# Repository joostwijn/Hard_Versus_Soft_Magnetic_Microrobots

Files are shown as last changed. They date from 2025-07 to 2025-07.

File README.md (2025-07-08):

# Hard_Versus_Soft_Magnetic_Microrobots

This repository supports the paper *"Propulsion Performance Comparison of Hard- and Soft-Magnetic Microrobots Under Rotating Magnetic Fields."* 
It contains all files needed to reproduce the experimental setup, control electronics, magnetic array optimization, and microrobot designs.

**Repository Structure**  
The repository is divided into four main chapters:

**1. Rotating Magnetic Field Setup** – All parts, bill of materials, SolidWorks assembly files, STL files for 3D printing, and DXF files for laser cutting.  
**2. Electronics** – Wiring diagrams, manuals for the electronic components, Arduino code, and Nextion display code.  
**3. Magnetic Optimization Code** – Python script for optimizing the magnetic array.  
**4. Microrobots** – Microrobot designs, STL files, and pre-configured Formlabs files.

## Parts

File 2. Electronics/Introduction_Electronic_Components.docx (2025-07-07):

This file contains a brief explanation of the different electronic components used in the Rotating Magnetic Setup. These components include the 12V/5A power supply, Arduino UNO R3, Nema 17 stepper motor, DRV8825 stepper driver, and Nextion display 2.4 inch (NX3224T024). The wiring of these components can be found in the file ”Wire_Diagram”.

12V/5A power supply
The system is powered by a 12V/5A power supply, which in turn is connected to a 230V mains socket. For safety and convenience, the 230V supply first passes through a three-pin fused switch connector before reaching the power supply.
To protect the electronics from damaging voltage spikes, a 100μF (rated at 50V) capacitor is placed across the 12V power supply’s positive and negative terminals, mitigating any surge that might otherwise harm the components.
The 12V output is distributed in two ways: it directly powers the stepper motor and supplies the Arduino UNO R3.

Arduino UNO R3
The Arduino UNO R3 is used to communicate with the Nextion display and uses the Nextion’s input to drive the stepper motor. The Arduino is programmed using C++ in the dedicated Arduino IDE (https://www.arduino.cc/en/software). The Arduino features an onboard step-down converter that supports up to 12V, allowing it to operate safely while maintaining the ability to upload code via USB. When a USB cable is connected, the Arduino automatically switches to USB power. The Arduino’s regulated 5V output is used to power both the Nextion display and the stepper driver.

NEMA 17 stepper motor
The NEMA 17 stepper motor is powered directly by the 12V power supply and controlled through a stepper driver. The Arduino UNO sends pulse signals to the stepper driver based on input from the Nextion display, determining the motor's speed and direction. The NEMA 17 can deliver a torque of up to 5.0 kg·cm (0.49 N·m). If higher torque is required, a NEMA 23 stepper motor can be used, but this requires a different stepper driver.

The NEMA 17 generates significant noise and vibrations at low rotation speeds. These can be reduced by enabling microstepping (smaller steps result in fewer vibrations), lowering the current limit on the stepper driver (see next paragraph), and including rubber O-rings in the stepper motor mounting.

DRV8825 stepper driver
The DRV8825 stepper motor driver receives pulse signals from the Arduino UNO to control the NEMA 17 stepper motor. It supports microstepping up to 1/32 steps and operates at 8.2V to 45V, supplying up to 2.5A per coil with sufficient cooling. The current limit must be manually set using the build-in potentiometer to match the motor's rated current (see https://www.makerguides.com/drv8825-stepper-motor-driver-arduino-tutorial/ for instructions). A heatsink or active cooling is required at high currents (<1 A) to prevent overheating.

Nextion display 2.4 inch (NX3224T024)
The Nextion 2.4-inch (NX3224T024) display is a resistive touchscreen that operates independently from the Arduino. It communicates with the Arduino via a hexadecimal protocol, sending commands for speed, direction, and the number of turns the stepper motor should complete.

Using a separate UI module reduces processing load on the Arduino and enables independent display operation. The Nextion is programmed using the Nextion Editor, which provides a graphical interface for designing screens and handling interactions (https://nextion.tech/editor_guide/).

Code uploads require an ADLivery CP2102 USB-to-serial adapter, along with its corresponding driver (https://www.silabs.com/developer-tools/usb-to-uart-bridge-vcp-drivers?tab=downloads). Proper installation of the driver is necessary for successful communication between the computer and the display.

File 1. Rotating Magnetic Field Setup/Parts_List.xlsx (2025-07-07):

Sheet: Structural_Components
Component | Quantity | Notes
20x20x500 aluminum profile | 2
20x40x160 aluminum profile | 5
Angle backets 20x20 | 14
Nema-17 angle bracket | 1
O-ring 28x3.1 | 6 | Supports for the setup to reduce vibrations and noise
O-ring 6x1.9 | 4 | Used as washers for the mounting screws of the stepper motor to reduce vibrations and noise
Washer M5 | 45
T-nut M5 | 45
Nut M3 | 9
Hex. socket screw M5x12 | 45
Hex. socket screw M3x6 | 17
Hex. socket screw M3x8 | 2
Hex. socket screw M3x20 | 1
Hex. Bolt M3x8 | 4
Threaded inserts M3x4x5 | 8
Nylon M3x12 screw | 4
Nylon M3 nut | 4

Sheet: Manufactured_Parts
Component | Quantity | Manufacturing technique | Material
Electronics mounting plate | 1 | 3D printing (FDM) | PLA
Stepper motor coupling | 1 | 3D printing (FDM) | PLA
Axis coupling | 1 | 3D printing (FDM) | PLA
Magnetic array | 2 | 3D printing (FDM) | PLA
Hollow Axis | 1 | 3D printing (FDM) | PLA
Tube setter | 1 | 3D printing (FDM) | PLA
Tube cap | 2 | 3D printing (FDM) | PLA
Back plate electronic casing | 1 | Laser cutting | PMMA (t = 3mm)
Frontplate electronic casing | 1 | Laser cutting | PMMA (t = 3mm)
Left side plate electronic casing | 1 | Laser cutting | PMMA (t = 3mm)
Right side plate electronic casing | 1 | Laser cutting | PMMA (t = 3mm)
Back top plate electronic casing | 1 | Laser cutting | PMMA (t = 3mm)
Front top plate electronic casing | 1 | Laser cutting | PMMA (t = 3mm)

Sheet: Electronics
Component | Quantity | Notes
Nema 17 stepper motor | 1
DRV8825 stepper driver | 1
Arduino UNO R3 | 1
Arduino UNO R3 base | 1 | Included in Arduino UNO R3 package
Power Supply 12V/5A | 1
3-pin connector with switch and fuse | 1 | Fuse is included in package
Breadboard 1/2 size | 1
Nextion display 2.4 inch (NX3224T024) | 1
Dupont wires 20 mm | 24
Capacitor 100 μF | 1

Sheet: Magnets
Component | Quantity | Notes
NdFeB Magnets 5x5 mm N42 | 108

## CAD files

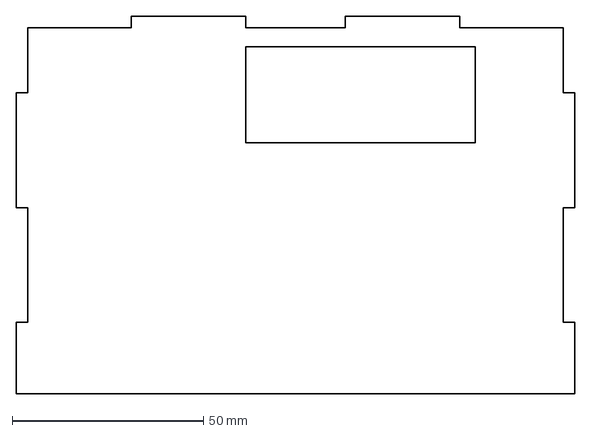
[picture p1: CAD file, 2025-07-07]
1. Rotating Magnetic Field Setup/DXF/PMMA_3mm_1x_TopPB.DXF
146.0 x 98.7 mm

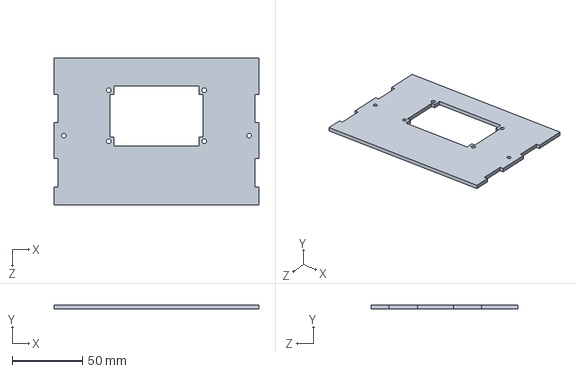
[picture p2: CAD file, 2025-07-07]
1. Rotating Magnetic Field Setup/SLDPRT/TopPlate_Front.SLDPRT
146.0 x 3.00 x 105.0 mm

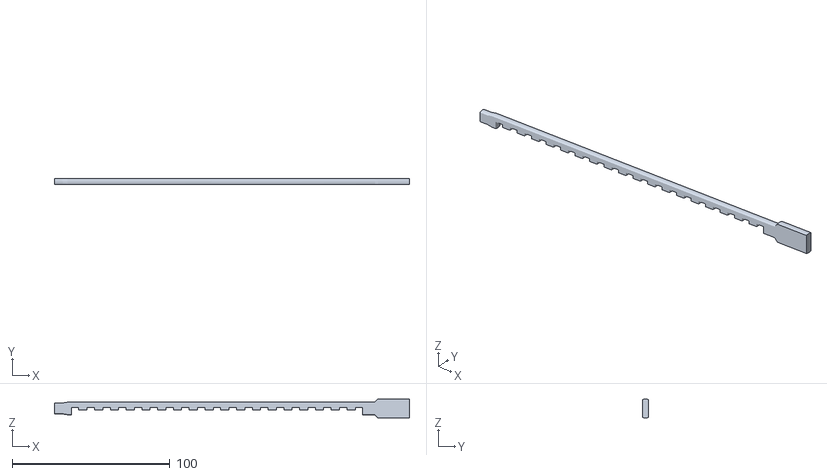
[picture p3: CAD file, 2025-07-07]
1. Rotating Magnetic Field Setup/STL/Measuring_Guide.STL
225.0 x 4.00 x 12.0

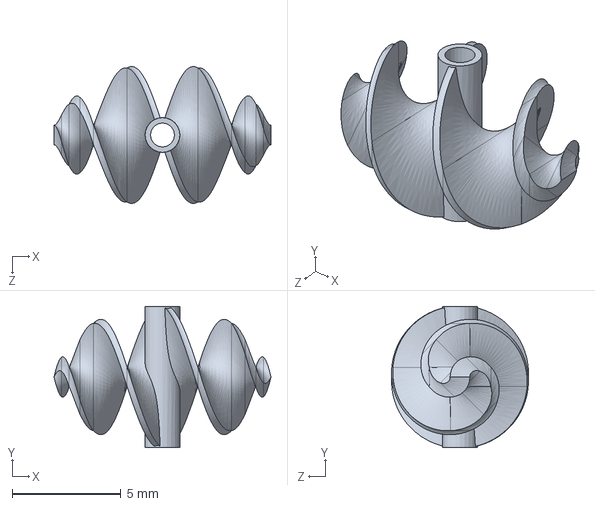
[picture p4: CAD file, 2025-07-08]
4. Microrobots/Designs/Ribbon_Soft_Magnet.SLDPRT
10.0 x 6.50 x 6.31 mm

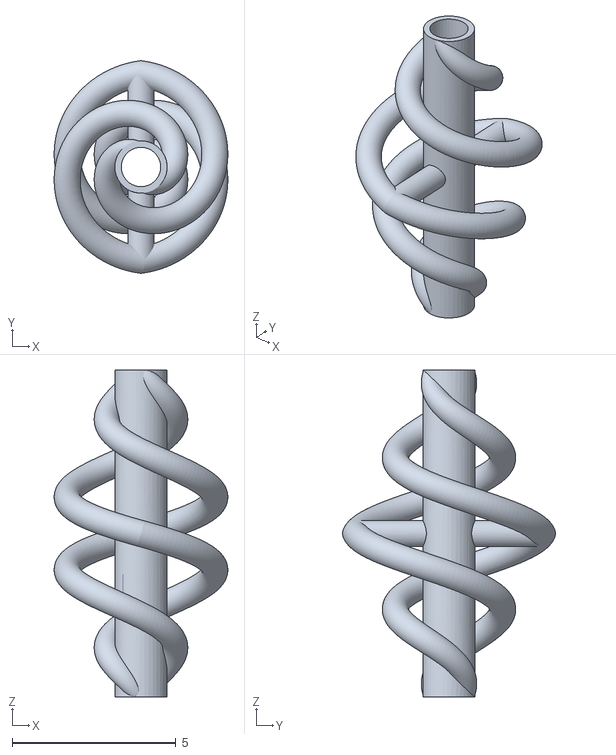
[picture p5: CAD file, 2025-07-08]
4. Microrobots/STL/Tapered_Helix_Hard_Magnet.STL
5.31 x 6.50 x 10.0

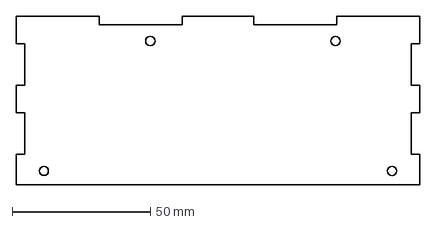
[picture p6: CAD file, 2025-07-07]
1. Rotating Magnetic Field Setup/DXF/PMMA_3mm_1x_BackP.DXF
146.0 x 61.0 mm

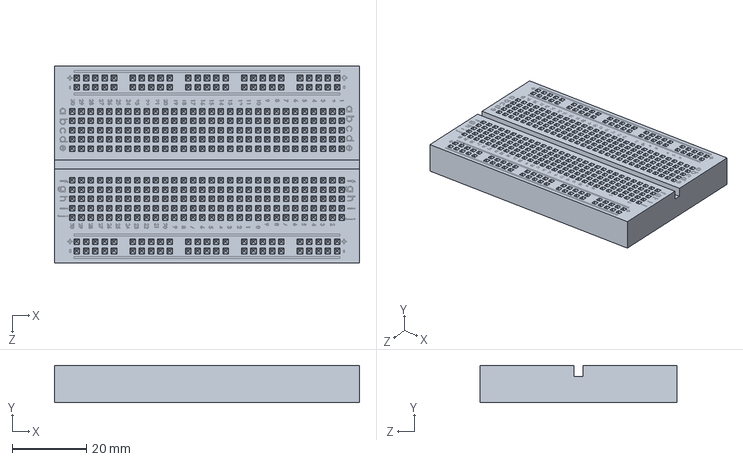
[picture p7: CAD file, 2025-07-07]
1. Rotating Magnetic Field Setup/SLDPRT/Breadboard.SLDPRT
82.0 x 10.0 x 53.0 mm

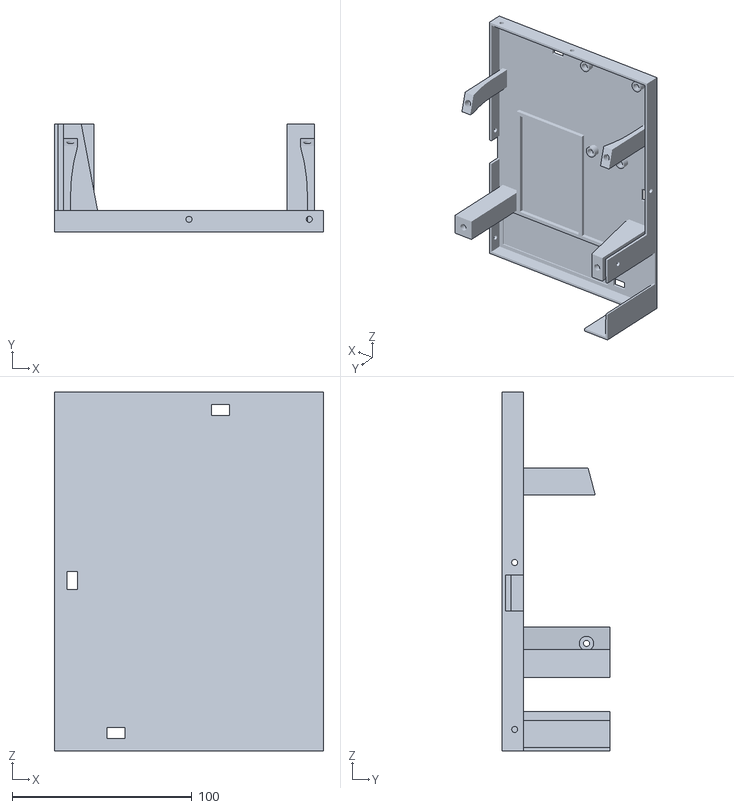
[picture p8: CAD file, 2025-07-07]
1. Rotating Magnetic Field Setup/STL/Electric_Bottom_Plate.STL
150.0 x 60.0 x 200.0

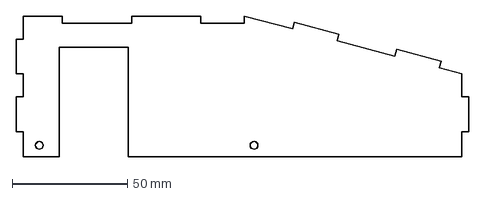
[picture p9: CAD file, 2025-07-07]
1. Rotating Magnetic Field Setup/DXF/PMMA_3mm_1x_LeftSP.DXF
196.0 x 61.0 mm

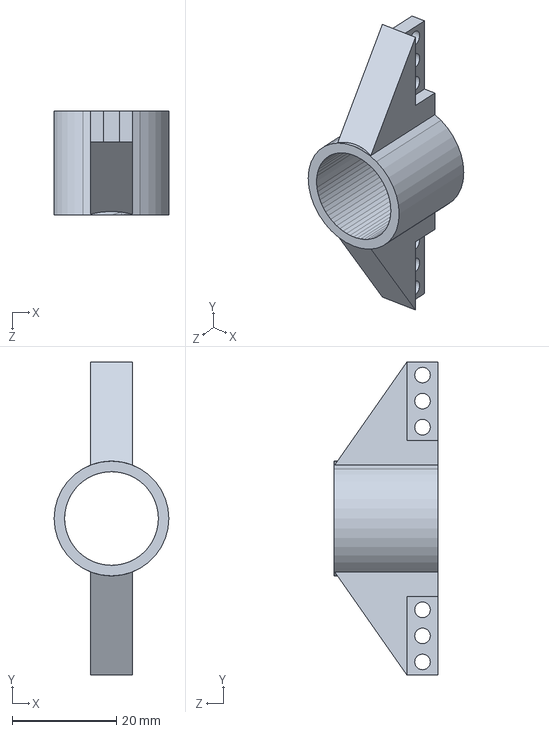
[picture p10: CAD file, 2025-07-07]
1. Rotating Magnetic Field Setup/SLDPRT/Mount_Right.SLDPRT
22.0 x 60.0 x 20.0 mm

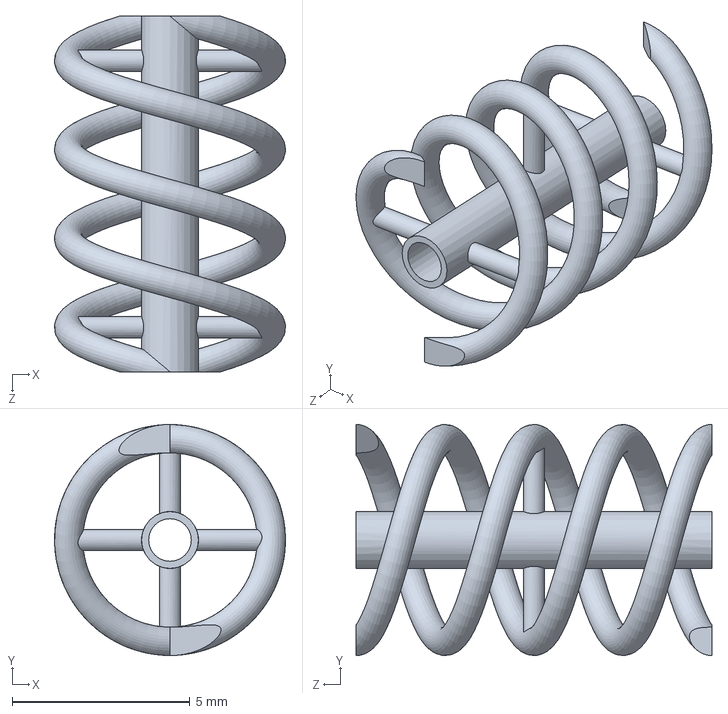
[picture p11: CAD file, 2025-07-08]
4. Microrobots/Designs/Helix_Hard_Magnet.SLDPRT
6.50 x 6.50 x 10.0 mm

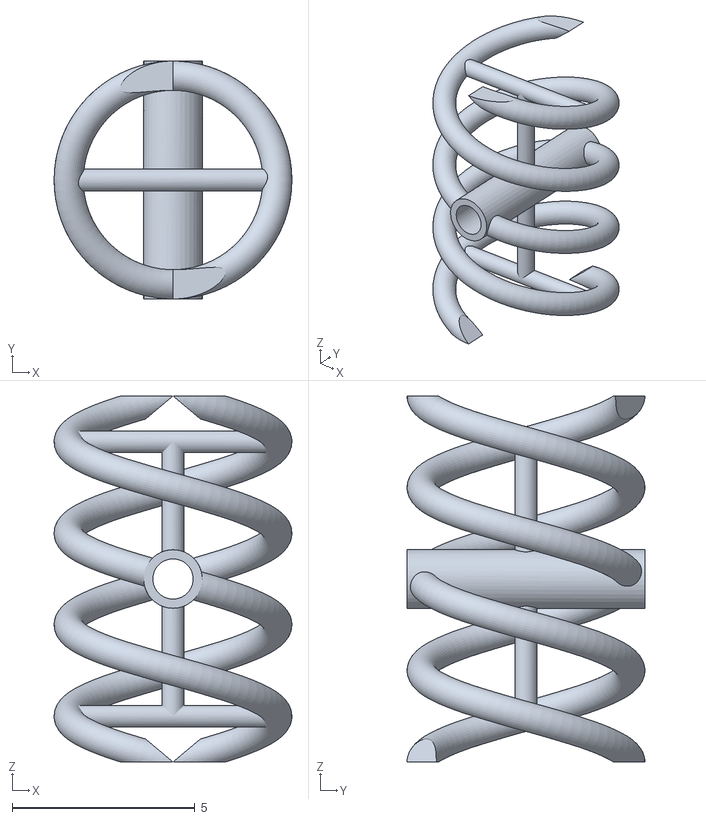
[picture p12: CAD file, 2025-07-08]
4. Microrobots/STL/Helix_Soft_Magnet.STL
6.50 x 6.50 x 10.00

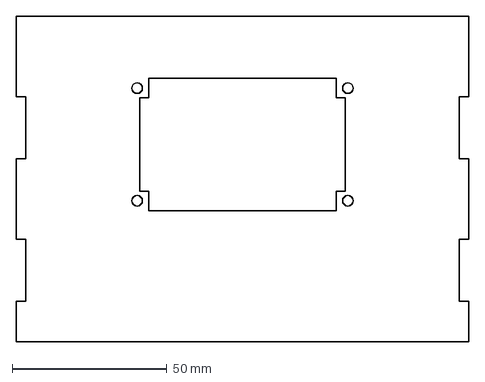
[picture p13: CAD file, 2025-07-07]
1. Rotating Magnetic Field Setup/DXF/PMMA_3mm_1x_TopPF.DXF
146.0 x 105.0 mm

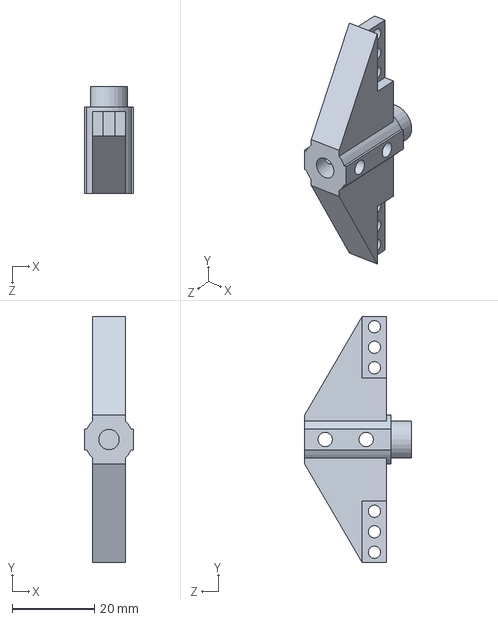
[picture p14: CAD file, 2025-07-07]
1. Rotating Magnetic Field Setup/SLDPRT/Mount_Left.SLDPRT
12.0 x 60.0 x 26.0 mm

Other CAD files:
4. Microrobots/Designs/Tapered_Helix_Hard_Magnet.SLDPRT
4. Microrobots/STL/Ribbon_Soft_Magnet.STL
4. Microrobots/Designs/Ribbon_Hard_Magnet.SLDPRT
4. Microrobots/STL/Ribbon_Hard_Magnet.STL
1. Rotating Magnetic Field Setup/DXF/PMMA_3mm_1x_FrontP.DXF
1. Rotating Magnetic Field Setup/DXF/PMMA_3mm_1x_RightSP.DXF
1. Rotating Magnetic Field Setup/SLDPRT/2020_Single_ALPROFILE_500mm.SLDPRT
1. Rotating Magnetic Field Setup/SLDPRT/2040_Double_ALPROFILE_160mm.SLDPRT
1. Rotating Magnetic Field Setup/SLDPRT/Arduino_UNO_Rev3_Base.SLDPRT
1. Rotating Magnetic Field Setup/SLDPRT/Axis.SLDPRT
1. Rotating Magnetic Field Setup/SLDPRT/BackPlate.SLDPRT
1. Rotating Magnetic Field Setup/SLDPRT/Bracket_90deg.SLDPRT
1. Rotating Magnetic Field Setup/SLDPRT/Connector_Switch_And_Fuse.SLDPRT
1. Rotating Magnetic Field Setup/SLDPRT/Electronic_Bottom_Plate.SLDPRT
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

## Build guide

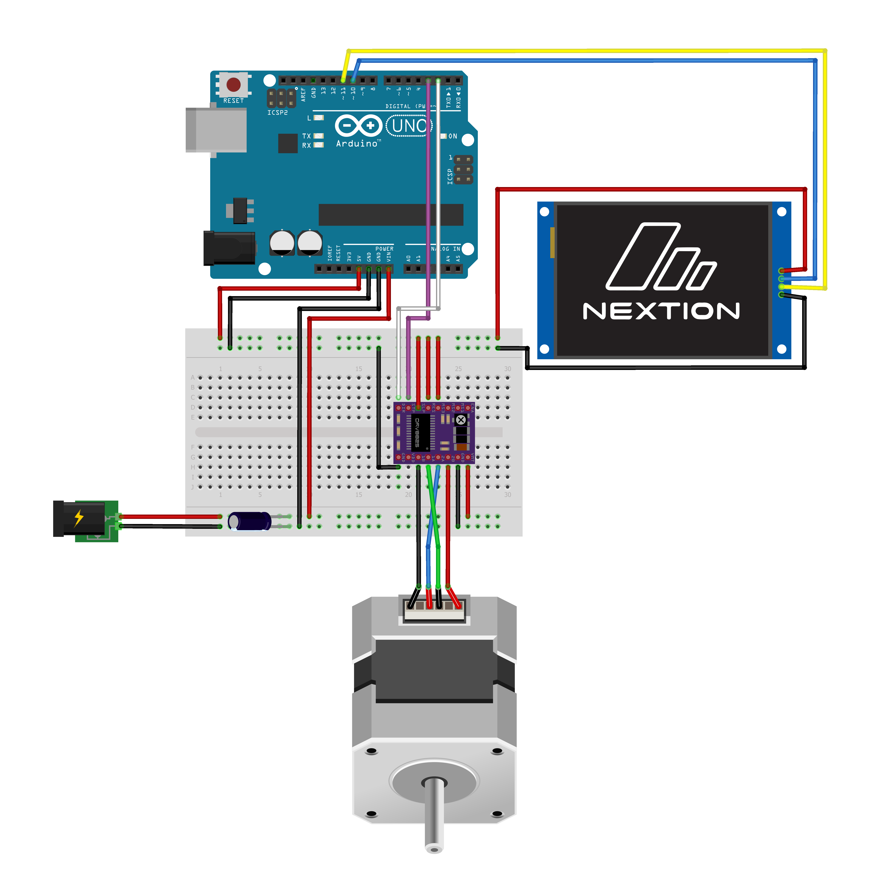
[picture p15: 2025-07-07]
2. Electronics/Wiring_Diagram_bb.png

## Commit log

2025-07-07 Parts
    Parts
    [2020_Single_ALPROFILE_500mm.SLDPRT, 2040_Double_ALPROFILE_160mm.SLDPRT, Arduino_UNO_Rev3_Base.SLDPRT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]
2025-07-08 Designs Added
    All Designs Added
    [Helix_Hard_Magnet.SLDPRT, Helix_Hard_Magnet.STL, Helix_Soft_Magnet.SLDPRT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]
